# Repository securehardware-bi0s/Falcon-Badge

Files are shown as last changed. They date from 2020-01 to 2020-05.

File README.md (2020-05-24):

# Falcon-Badge

**Work in progress.**
**Check the OTA branch**

## Layout
```
├── bin
│   ├── falcon-fire.bin
│   ├── final-unlocked.bin
│   ├── game_of_life.bin
│   ├── initial.bin
│   └── serial-exploitation.bin
├── hw
│   ├── Assembly
│   ├── DrillFiles
│   ├── GerberFiles
│   ├── InCTF_Badge.brd
│   └── InCTF_Badge.sch
├── LICENSE
├── README.md
└── src
    ├── falcon-fire
    ├── Final
    ├── Game-Of-Life
    ├── initial
    │   ├── data
    └── serial-exploitation
```
### Software Pre-requisities
Software to install:
* For Windows:
    * [USB-UART Driver](https://www.silabs.com/products/development-tools/software/usb-to-uart-bridge-vcp-drivers)
* On Linux/Windows:
    * pyserial -> ```pip install pyserial```
    * esptool -> ```pip install esptool```
        * For more info visit [esptool](https://github.com/espressif/esptool).
    * miniterm.py (Installed with pyserial)

### Binaries

* falcon-fire.bin
    * A version of the 80s *Asteroid* Game.
* final-unlocked.bin
    * Firmware with unlocked LEDs and defence against laser attacks.
* game_of_life.bin
    * A version of *Conway's Game of Life* on Falcon.
* initial.bin
    * The basic firmware everyone's badge was loaded with.
* serial-exploitation.bin
    * Firmware that was designed to teach you serial exploitation.

### How to flash the firmware?

Make sure you've installed the correct drivers and the ```esptool.py```
Clone the repository and open a terminal in the same directory.
Run the following command with the desired file in the same terminal.
```
esptool.py write_flash 0x00000 initial.bin
```
### Source Code
The code is written with the help of [Arduino](https://github.com/esp8266/Arduino) SDK, considering it to be beginner-friendly platform. You can run [MicroPython](https://docs.micropython.org/en/latest/esp8266/tutorial/intro.html) on the same board as well.
#### The structure
The badge has the personal data of the users stored in the SPIFFS system. Hence we use the 4MB flash memory in NodeMCU with 1MB specified for filesystem.
If you're interested in learning more about the [Filesystem](https://arduino-esp8266.readthedocs.io/en/latest/filesystem.html) used in ESP8266 Arduino. 
This filesystem consists of the following files:
```
data/
├── chall.png -> The forensics challenge desgined by @_f41c0n
├── flag -> For the game 
├── id -> Cadet/Padawan/Rebel ID
├── ip -> Static IP Assigned to each badge
├── name -> Username
├── pass -> 5 char of username and 5 char of the phone number

```
#### Some of the used libraries include
* [ThingPulse SSD1306](https://github.com/ThingPulse/esp8266-oled-ssd1306)
* [Adafruit GFX](https://github.com/adafruit/Adafruit-GFX-Library)
* [Adafruit SSD1306](https://github.com/adafruit/Adafruit_SSD1306)
* [u8g2](https://github.com/olikraus/u8g2)
* Already included in the base installation
    * Wire
    * FS
#### How to compile? 
* If you have successfully installed Arduino IDE , you can just clone the code to get started.

Warning

You might face an issue of creating a new folder, just press "OK" and continue.
* If you like the makefile approach then I suggest you look at [makeEspArduino](https://github.com/plerup/makeEspArduino) project.
    * To build 
        ```make -f makeEspArduino.mk all FLASH_DEF=4M1M```
    * For flashing the code 
        ```make -f makeEspArduino.mk flash FLASH_DEF=4M1M```
    * For flashing the filesystem 
        ```make -f makeEspArduino.mk flash_fs FLASH_DEF=4M1M```
        
### Write-Ups 
<h3>You sure?</h3><details>

## Web Challenge
`?id=100` gives the correct flag

## Image Challenge
There is a base64 text appended to the image. Extracting and decoding it will give a table of 8 columns representing the 8 bits of each character.
Extract the binary data and decode it to get the flag.

## Serial Exploitation
The challenge starts with a login screen and on choosing the login option requires you to enter a randomly generated OTP. On analysis we can see that the LDR which is connected to the analog pin of the NodeMCU is used as the random seed for generating pseudo-random values. 

If we short the analog pin with the VCC the random seed value will remain constant and so the pattern of generated OTP will remain constant. So by using a sample code to generate the OTP pattern or by brute-force you can login to the system.

Once you login, you will get an option to read data from the board. You only have permission to read a maximum of 50 characters. But the array from which you are reading data is a byte array of size 260. The input given is to a signed 8 bit variable and the program first checks if the value is greater less than 50. After the initial condition is passed the value is moved to an unsigned 8 bit variable and then that many number of characters from the array is printed. So if we enter a negative number like ‘-1’ it will bypass the initial check and when the value is moved to the unsigned variable -1 becomes 255 and we can read 255 characters from the array. The flag is stored from the 188th index so the output we get by giving -1 as the input will contain the flag!

FLAG : falcon{y0u_3xtr4ct3d_th3_s3ctr3t_d4t4}
</details>

### To-Do

* [x] Add Source Code
* [x] Add OTA and MQTT Code (Check the OTA branch)
* [x] Add Write-Ups

### Credits

GameOfLife based on: [DrMikeG](https://raw.githubusercontent.com/DrMikeG/Conway/master/GameOfLife/GameOfLife.ino)

Falcon-Fire based on: [pauls-3d-things](https://github.com/pauls-3d-things/arduino-space-hopper)

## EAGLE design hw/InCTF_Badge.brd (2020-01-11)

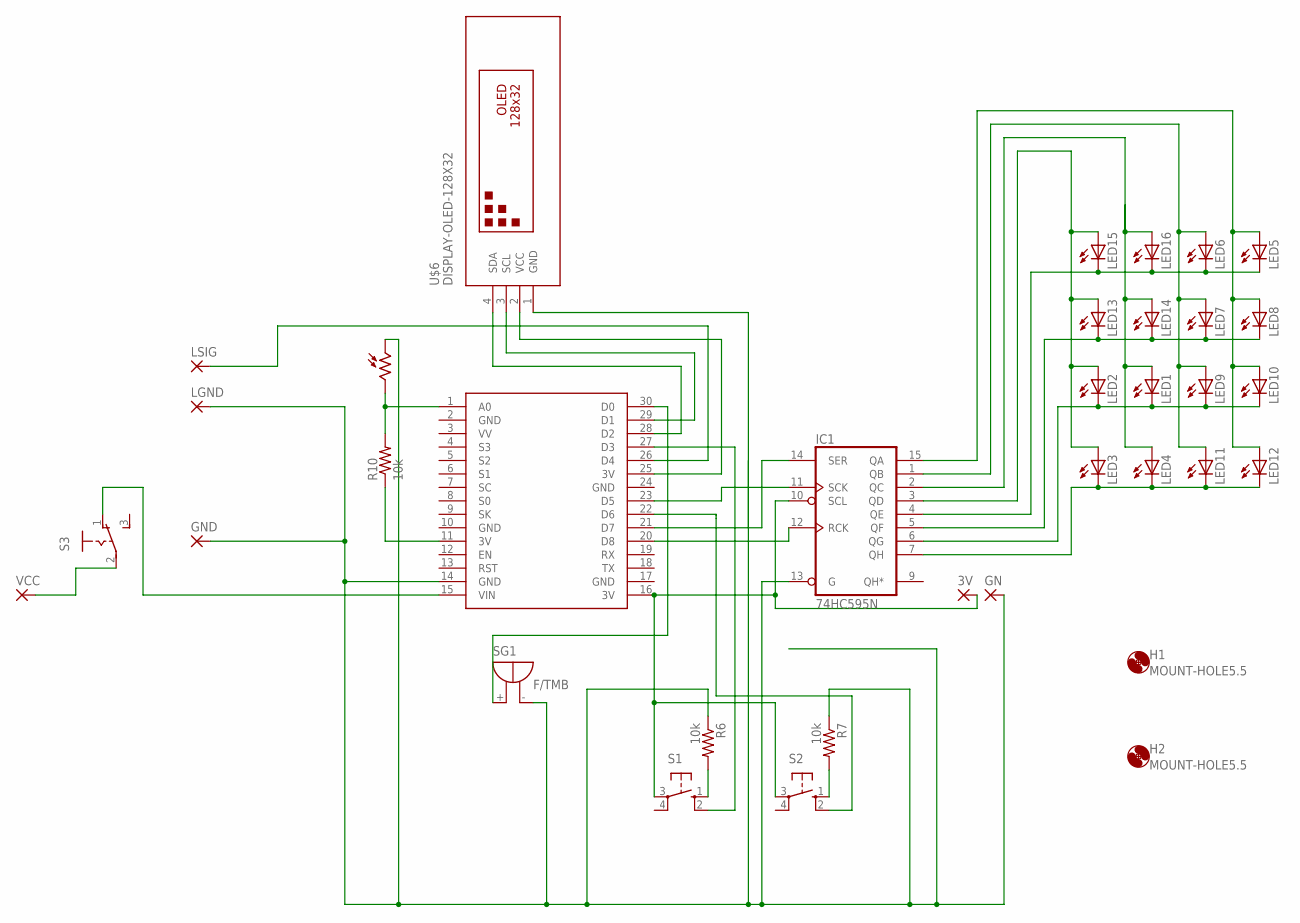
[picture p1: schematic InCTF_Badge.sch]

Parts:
3V: 1,6/0,8
GN: 1,6/0,8
GND: 1,6/0,8
H1, H2: MOUNT-HOLE5.5; 5,5
IC1: 74HC595N; DIL16
LED1, LED2, LED3, LED4, LED5, LED6, LED7, LED8, LED9, LED10, LED11, LED12, LED13, LED14, LED15, LED16: LED5MM
LGND: 1,6/0,8
LSIG: 1,6/0,8
PH1: A1050_09; T0-46-A10XX
R6, R7, R10: 10k; 0204/5
S1, S2: 10-XX; B3F-10XX
S3: 255SB
SG1: F/TMB
U$1: NODEMCU
U$6: DISPLAY-OLED-128X32
VCC: 1,6/0,8

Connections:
GND: U$1.10 (GND), U$1.17 (GND), U$1.24 (GND)
unnamed: IC1.14 (SER), U$1.21 (D7)
unnamed: U$1.29 (D1), U$6.3 (SCL)
unnamed: U$1.28 (D2), U$6.4 (SDA)
unnamed: U$1.25 (3V), U$6.2 (VCC)
unnamed: IC1.12 (RCK), U$1.20 (D8)
unnamed: IC1.11 (SCK), U$1.23 (D5)
unnamed: S3.1 (O), U$1.15 (VIN)
unnamed: S1.2 (S1), U$1.27 (D3)
unnamed: LSIG.1, U$1.26 (D4)
unnamed: IC1.4 (QE), LED5.K (C), LED6.K (C), LED15.K (C), LED16.K (C)
unnamed: IC1.5 (QF), LED7.K (C), LED8.K (C), LED13.K (C), LED14.K (C)
unnamed: IC1.6 (QG), LED1.K (C), LED2.K (C), LED9.K (C), LED10.K (C)
unnamed: IC1.7 (QH), LED3.K (C), LED4.K (C), LED11.K (C), LED12.K (C)
unnamed: S3.2, VCC.1
unnamed: R10.1, U$1.11 (3V)
unnamed: SG1.+, U$1.30 (D0)
unnamed: IC1.3 (QD), LED2.A, LED3.A, LED13.A, LED15.A
unnamed: IC1.2 (QC), LED1.A, LED4.A, LED14.A, LED16.A
unnamed: IC1.1 (QB), LED6.A, LED7.A, LED9.A, LED11.A
unnamed: IC1.15 (QA), LED5.A, LED8.A, LED10.A, LED12.A
unnamed: 3V.1, IC1.10 (SCL), S1.3, S2.3, U$1.16 (3V)
unnamed: R6.2, S1.1 (S)
unnamed: R7.2, S2.1 (S)
unnamed: PH1.2, R10.2, U$1.1 (A0)
unnamed: IC1.8 (GND), U$1.2 (GND)
S2: S2.2 (S1), U$1.22 (D6)
V: GN.1, GND.1, IC1.13 (G), LGND.1, PH1.1, R6.1, R7.1, SG1.-, U$1.14 (GND), U$6.1 (GND)
VCC: IC1.16 (VCC)

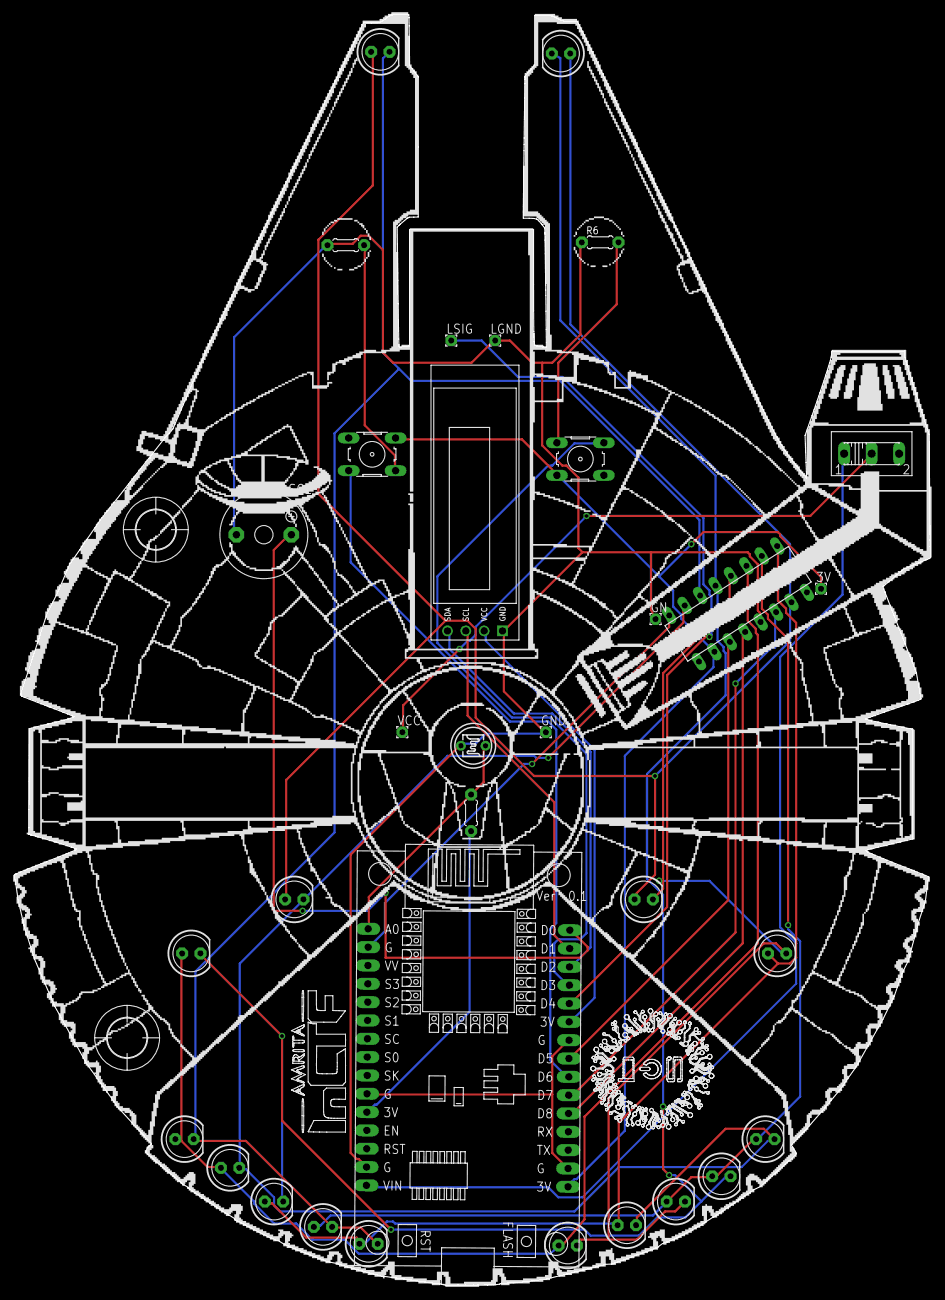
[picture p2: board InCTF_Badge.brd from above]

Board: 2 copper layers, 126.9 x 176.2 mm, 35 parts (0 on the bottom side), 28 nets.

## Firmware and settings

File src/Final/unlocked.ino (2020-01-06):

/**
 * Init-Firmware
 * The MIT License (MIT)
 *
 * Copyright (c) 2019 by Securehardware@bi0s
 *
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
 */
// Pin Declarations for the modules in the Kit
const int laserPin = 0;
const int dataPin = 13;  
const int loadPin = 15;  
const int clockPin = 14;
const int cntrl_1Pin = 12; // Pin D6
const int cntrl_2Pin = 16; // Pin D0

/////////////////////////////////////////////////////////////////////
/////////////////////////////////////////////////////////////////////
// Libraries Included for modules
#include <Wire.h>
#include "SSD1306Wire.h"
#include <FS.h>

SSD1306Wire display(0x3c, 4, 5, GEOMETRY_128_32);
ESP8266WebServer server(8266);

// Custom Header Files
#include "images.h"

/////////////////////////////////////////////////////////////////////
#ifndef STASSID
#define STASSID "AMRITA-LAN"
#endif
////////////////////////////////////////////////////////////////////
const char* mqttServer = "10.112.7.254";
const int mqttPort = 1883;
///////////////////////////////////////////////////////////////////
IPAddress gateway(10, 112, 0, 1);   //IP Address of your WiFi Router (Gateway)
IPAddress subnet(255, 255, 248, 0);  //Subnet mask
////////////////////////////////////////////////////////////////////
WiFiClient espClient;
PubSubClient client(espClient);
////////////////////////////////////////////////////////////////////
#define DEMO_DURATION 4000
typedef void (*Demo)(void);

int demoMode = 0;
int counter = 1;
int randX = 0;
int randY = 0;
////////////////////////////////////////////////////////////////////
const char* ssid = STASSID;
const char* upad;
const char* upasswd;
const char* mqttClientID;
const char* char_ip;
String name;
String cred;
String id;
String s_ip;

///////////////////////////////////////////////////////////////////
void LED_Matrix() {
  byte data = B00001111;
  digitalWrite(loadPin, LOW);
  shiftOut(dataPin, clockPin, MSBFIRST, data);
  digitalWrite(loadPin, HIGH);
  digitalWrite(laserPin, HIGH);
  delay(100);  
  data = B00000000;
  digitalWrite(loadPin, LOW);
  shiftOut(dataPin, clockPin, MSBFIRST, data);
  digitalWrite(loadPin, HIGH);
  digitalWrite(laserPin, HIGH);
  delay(50);  
  Serial.println("Bleh Bleh");
}
///////////////////////////////////////////////////////////////////
void particleDraw()
{
  for(int j=0;j<20;j++)
  {
    yield();
    randX=random(0,128);
    randY=random(0,32);
    display.setPixel(randX,randY);
  }
  LED_Matrix();
}
///////////////////////////////////////////////////////////////////
void inctf_logo() {
    display.drawXbm(0, 0,Logo_width,Logo_height,inctf);
}
/////////////////////////////////////////////////////////////////////
void disp_name() {
    display.setTextAlignment(TEXT_ALIGN_LEFT);
    display.setFont(ArialMT_Plain_10);
    display.drawString(0, 0, "Hi, My name is ");
    display.setFont(ArialMT_Plain_16);
    display.drawString(0,10,name);
}
/////////////////////////////////////////////////////////////////////
void disp_id() {
    display.setTextAlignment(TEXT_ALIGN_LEFT);
    display.setFont(ArialMT_Plain_16);
    display.drawString(0, 0, "ID");
    display.setFont(ArialMT_Plain_10);
    display.drawString(0,16,id);
}
/////////////////////////////////////////////////////////////////////
void handcraft() {
    display.setTextAlignment(TEXT_ALIGN_LEFT);
    display.setFont(ArialMT_Plain_10);
    display.drawString(0, 0, "Handcrafted by");
    display.setFont(ArialMT_Plain_16);
    display.drawString(0,10,"bi0s");
}
/////////////////////////////////////////////////////////////////////
void callback(char* topic, byte* payload, unsigned int length) {
 
  String message;
  for (int i = 0; i < length; ++i) {
    Serial.print((char)payload[i]);
  }
 
  message = (char*)payload;
  if ((char)payload[0]) {
    display.clear();
    display.setTextAlignment(TEXT_ALIGN_LEFT);
    display.setFont(ArialMT_Plain_10);
    display.drawString(0, 0, message);
    display.setFont(ArialMT_Plain_16);
    display.drawString(0,10 , "-----");
    display.setFont(ArialMT_Plain_10);
    display.display();
    delay(5000);
    display.clear();
    display.display();
    message = "                                                                                   ";
 
  }
 
  Serial.println();
  Serial.println("-----------------------");
 
}
//////////////////////////////////////////////////////////////////////////
void parseBytes(const char* str, char sep, byte* bytes, int maxBytes, int base) {    

for (int i = 0; i < maxBytes; i++) {        
bytes[i] = strtoul(str, NULL, base);  
 str = strchr(str, sep);          
if (str == NULL || *str == '\0') {          
  break;                        
}    
    str++;                    
    }}

//////////////////////////////////////////////////////////////////////////
void setup()
{
  pinMode(laserPin,OUTPUT);
  pinMode(dataPin, OUTPUT);
  pinMode(loadPin, OUTPUT);
  pinMode(clockPin, OUTPUT);
  // Debug Enable
  Serial.begin(115200);
  digitalWrite(laserPin, HIGH);

  // Display Init
  display.init();
  display.flipScreenVertically();
  display.setFont(ArialMT_Plain_10);
  // FS Init
  if(!SPIFFS.begin()){
    Serial.println("An Error has occurred while mounting SPIFFS");
    return;
  }
// Calling FS Values

  File  spiffs_name = SPIFFS.open("/name", "r");
   if (!spiffs_name) {
      Serial.println("file open failed");
  }   Serial.println("---Reading from Name---");
  name=spiffs_name.readStringUntil('\n');
  spiffs_name.close();

  File  spiffs_ip = SPIFFS.open("/ip", "r");
   if (!spiffs_ip) {
      Serial.println("file open failed");
  }   Serial.println("---Reading from IP---");
  s_ip=spiffs_ip.readStringUntil('\n');
  spiffs_ip.close();
 
  File  spiffs_id= SPIFFS.open("/id", "r");
   if (!spiffs_id) {
      Serial.println("file open failed");
  }   Serial.println("---Reading from ID---");
  id=spiffs_id.readStringUntil('\n');
  spiffs_id.close();

  File  spiffs_pass= SPIFFS.open("/pass", "r");
   if (!spiffs_pass) {
      Serial.println("file open failed");
  }   Serial.println("---Reading from Creds---");
  cred=spiffs_pass.readStringUntil('\n');
  spiffs_pass.close();

 upad=name.c_str();
 upasswd=cred.c_str();
 mqttClientID=id.c_str();
 char_ip=s_ip.c_str();
// Debug Purposes
// Serial.println(upad);
// Serial.println(upasswd);
// Serial.println(mqttClientID);

// String IP conversion
  byte dec_ip[4];
  parseBytes(char_ip,'.',dec_ip,4,10);
  dec_ip[0] = (uint8_t)dec_ip[0];          
  dec_ip[1] = (uint8_t)dec_ip[1];          
  dec_ip[2] = (uint8_t)dec_ip[2];          
  dec_ip[3] = (uint8_t)dec_ip[3];            
 IPAddress ip_static(dec_ip[0],dec_ip[1],dec_ip[2],dec_ip[3]);

Demo demos[] = {disp_name,particleDraw,inctf_logo,handcraft};
int demoLength = (sizeof(demos) / sizeof(Demo));
long timeSinceLastModeSwitch = 0;

/////////////////////////////////////////////////////////////////////
void loop()
{

   server.handleClient();
   display.clear();
  // draw the current demo method
  demos[demoMode]();

  display.setFont(ArialMT_Plain_10);
  // write the buffer to the display
  display.display();


  if (millis() - timeSinceLastModeSwitch > DEMO_DURATION) {
    demoMode = (demoMode + 1)  % demoLength;
    timeSinceLastModeSwitch = millis();

  }
  counter++;
  delay(100);
 
}
/////////////////////////////////////////////////////////////////////

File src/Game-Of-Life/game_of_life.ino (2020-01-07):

#include <Wire.h>
#include <Adafruit_GFX.h>
#include <Adafruit_SSD1306.h>
#include <FS.h>
String name;
String cred;
String id;
String s_ip;
// STASSID is 128x64
#define OLED_RESET -1
Adafruit_SSD1306 display(128,32,&Wire,OLED_RESET);

//Current grid, max is 64x32 for 2048 byte Uno...
// width must be multiple of 8
// 8.6 iterations / second
const uint8_t width = 64;
const uint8_t height = 16;
const uint8_t pixelSize = 2;
const boolean displayIterations = true;
const uint16_t maxGenerations = 1000;

uint8_t grid[width / 8 * height];
// should be possible to do without full copy buffer, but how ?
uint8_t newgrid[width / 8 * height];

static const uint8_t PROGMEM
        GFXsetBit[] = { 0x80, 0x40, 0x20, 0x10, 0x08, 0x04, 0x02, 0x01 },
        GFXclrBit[] = { 0x7F, 0xBF, 0xDF, 0xEF, 0xF7, 0xFB, 0xFD, 0xFE };

inline void setPixel(uint8_t* ptr, uint8_t x, uint8_t y, uint8_t color) {
  uint16_t idx = (x + y * width)  / 8;  
  if (color == 1) {
    //     ptr[idx] |= (0x80 >> (x & 7));
    // >> is slow on AVR (Adafruit)
    ptr[idx] |= pgm_read_byte(&GFXsetBit[x & 7]);
  } else {
    //     ptr[idx] &= ~(0x80 >> (x & 7));
    ptr[idx] &= pgm_read_byte(&GFXclrBit[x & 7]);
  }
}

inline uint8_t getPixel(uint8_t* ptr, uint8_t x, uint8_t y) {
  uint16_t idx = (x + y * width) / 8;
//  uint8_t value = ptr[idx] & (0x80 >> (x & 7));
  uint8_t value = ptr[idx] & pgm_read_byte(&GFXsetBit[x & 7]);
  return value == 0 ? 0 : 1;
}

//Draws the grid on the display
void drawGrid(uint16_t gen) {
  display.clearDisplay();
  uint8_t offsetx = (128 - (width * pixelSize)) / 2;
  uint8_t offsety = (32 - (height * pixelSize)) / 2;
 #if 1
    for (uint8_t y = 1; y < (height - 1); y++) {
      for (uint8_t x = 1; x < (width - 1); x++) {
        uint8_t color = getPixel(grid, x, y); 
        if (color == WHITE) {
          //if (pixelSize == 1) // does not seem any faster
          //  display.drawPixel(offsetx + pixelSize*x, offsety + pixelSize*y, WHITE);
         // else 
            display.fillRect(offsetx + pixelSize*x, offsety + pixelSize*y, pixelSize, pixelSize, WHITE);
        }
    }
  }
  #else
  // works for size 1, draw directly the bitmap into the frame buffer
    display.drawBitmap(offsetx, offsety, grid, width, height, WHITE, BLACK);
  #endif
  if (displayIterations && gen) {
    display.setTextSize(1);
     display.setCursor(0,0);
     display.print(gen);
  }
  display.display();
}

//Initialize Grid
void initGrid() {
    for (uint8_t y = 0; y < height; y++) {
       for (uint8_t x = 0; x < width; x++) {
        if (x==0 || x==(width - 1) || y==0 || y== (height - 1)){
          setPixel(grid, x, y, 0);
        } else {
            setPixel(grid, x, y, random(2)); 
        }
    }   
  }
}
// order makes faster code ?
inline uint8_t getNumberOfNeighbors(uint8_t x, uint8_t y){
    return getPixel(grid, x-1, y)+
  getPixel(grid, x+1, y)+
  getPixel(grid, x-1, y-1)+
  getPixel(grid, x, y-1)+
  getPixel(grid, x+1, y-1)+
  getPixel(grid, x-1, y+1)+
  getPixel(grid, x, y+1)+
  getPixel(grid, x+1, y+1);
}

void computeNewGeneration(){
    for (uint8_t y = 1; y < (height - 1); y++) {
      for (uint8_t x = 1; x < (width - 1); x++) {
        uint8_t neighbors = getNumberOfNeighbors(x, y);
        uint8_t current = getPixel(grid, x, y);
        if (current == 1 && (neighbors == 2 || neighbors == 3 )) {
          setPixel(newgrid, x, y, 1);
        } else if (current==1)  
          setPixel(newgrid, x, y, 0);
        if (current==0 && (neighbors==3)) {
          setPixel(newgrid, x, y, 1);
        } else if (current==0) 
          setPixel(newgrid, x, y, 0);
    }  
  }
  // copy newgrid into grid
  memcpy(grid, newgrid, width * height / 8);
}

void parseBytes(const char* str, char sep, byte* bytes, int maxBytes, int base) {

for (int i = 0; i < maxBytes; i++) {
bytes[i] = strtoul(str, NULL, base);
 str = strchr(str, sep);
if (str == NULL || *str == '\0') {
  break;
}
    str++;
    }}

//////////////////////////////////////////////////////////////////////////
void setup()   {                
  Serial.begin(9600); //use only for debugging purposes
  randomSeed(analogRead(A0));
  display.begin(SSD1306_SWITCHCAPVCC, 0x3C); //initialize with the I2C addr 0x3C (128x64)
  display.display();
  delay(2000);
  display.setTextColor(WHITE, BLACK);

  if(!SPIFFS.begin()){
    Serial.println("An Error has occurred while mounting SPIFFS");
    return;
  }
// Calling FS Values

  File  spiffs_name = SPIFFS.open("/name", "r");
   if (!spiffs_name) {
      Serial.println("file open failed");
  }   Serial.println("---Reading from Name---");
  name=spiffs_name.readStringUntil('\n');
  spiffs_name.close();

  File  spiffs_ip = SPIFFS.open("/ip", "r");
   if (!spiffs_ip) {
      Serial.println("file open failed");
  }   Serial.println("---Reading from IP---");
  s_ip=spiffs_ip.readStringUntil('\n');
  spiffs_ip.close();

  File  spiffs_id= SPIFFS.open("/id", "r");
   if (!spiffs_id) {
      Serial.println("file open failed");
  }   Serial.println("---Reading from ID---");
  id=spiffs_id.readStringUntil('\n');
  spiffs_id.close();

  File  spiffs_pass= SPIFFS.open("/pass", "r");
   if (!spiffs_pass) {
      Serial.println("file open failed");
  }   Serial.println("---Reading from Creds---");
  cred=spiffs_pass.readStringUntil('\n');
  spiffs_pass.close();

// Debug Purposes
// Serial.println(upad);
// Serial.println(upasswd);
// Serial.println(mqttClientID);

}

void loop() {       
    //Displaying a simple splash screen
  display.clearDisplay();
  display.setTextSize(1);
  display.setCursor(0,15);
  display.print(F("Game of Life"));       
  display.display();
  delay(3500);

  display.clearDisplay();
  initGrid();
  drawGrid(0);
  delay(8000);    
//  int t = millis();
  for (uint16_t gen = 0; gen < maxGenerations; gen++) {
     computeNewGeneration();
     drawGrid(gen);
//     delay(20);
  } 
//  Serial.println(millis() - t);  
}

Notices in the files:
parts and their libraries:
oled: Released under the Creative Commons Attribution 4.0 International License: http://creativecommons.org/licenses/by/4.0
